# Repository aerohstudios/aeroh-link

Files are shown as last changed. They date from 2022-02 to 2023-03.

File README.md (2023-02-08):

# Aeroh Link

Internet Connected Infrared Remote for Alexa, Google Assitant, Apple Homekit (Siri) &amp; IFTTT integration

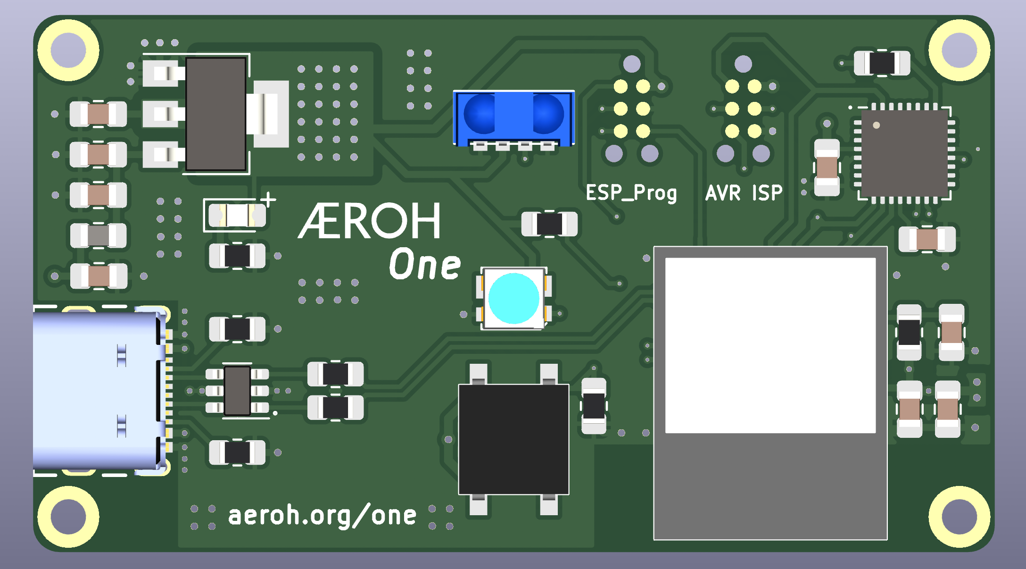
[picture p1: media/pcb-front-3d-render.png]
PCB Front 3D Render


## Description

The Aeroh Link is for the lazy people, the exhausted ones who can't be bothered to turn on their fans because they have to get out of the couch.

Aeroh Link is an internet-connected device that turns your tower fan into a smart fan. You can either use our mobile app or simply integrate it into your Alexa, Google Assistant, Siri, or IFTTT. And at 10th the price of a smart fan.

It doesn't end there. Aeroh Link can work with a wide range of tower fans in the market and it's adaptable to work with any device that can be controlled with remote control. Yes, even with your old TV.

Aeroh Link has a small footprint; it mounts on top of the infra-red remote receiver of your equipment and is programmed to emit the remote signals based on what your equipment can understand. We have a wide range of mounting options that you can either order or freely download the 3D models and print yourself if you have access to a 3D printer.

Moreover, You can still use your OEM remote while Aeroh Link is mounted on the equipment. This is because Aeroh One has an infra-red remote receiver in the front, and it can proxy the signals that it receives.

With this infra-red remote receiver, you can also record custom infra-red signals and program the Aeroh Link to work with new equipment.

With Aeroh Link, make your smart home smarter, and that too without breaking your bank!

## Photo Gallery

### Enclosure

**Front of the enclosure with IR Receiver Window, Status LED window and control button**

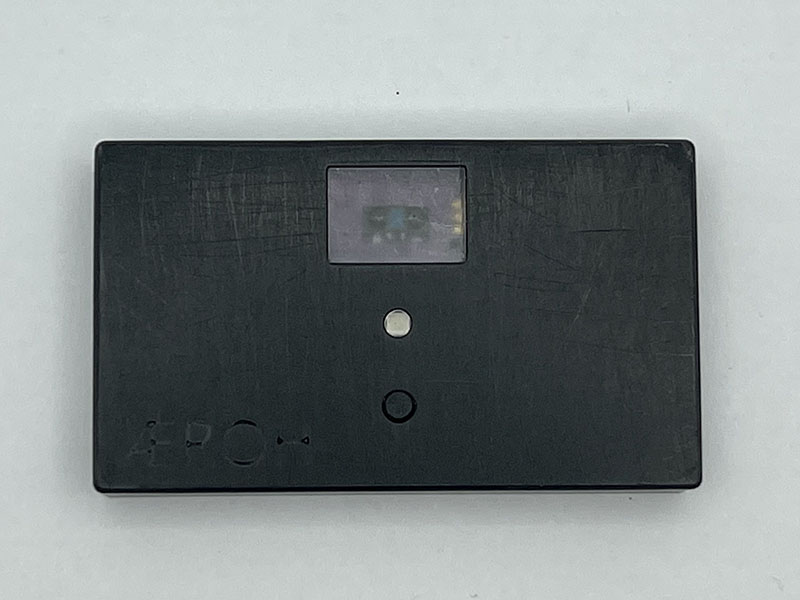
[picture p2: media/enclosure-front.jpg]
Enclosure Front


**Back of the enclosure with IR Emitter**

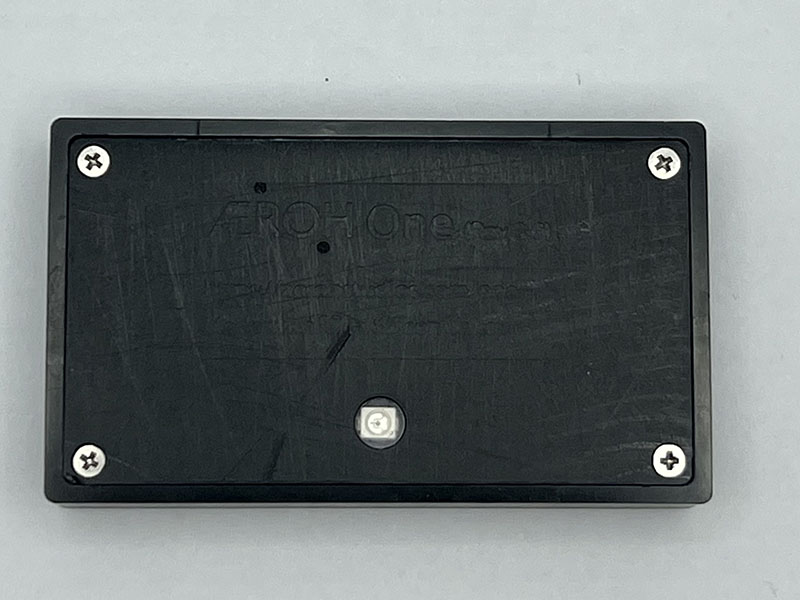
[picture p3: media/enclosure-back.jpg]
Enclosure Back


**USB-C Port for Power & Debugging**

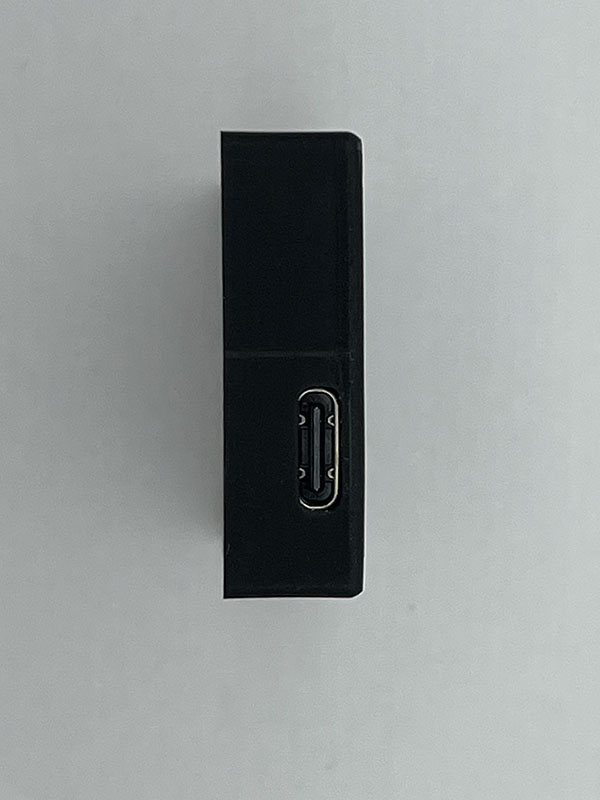
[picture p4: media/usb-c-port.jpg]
USB-C Port


### PCB

**Front of the PCB with IR Receiver, Status LED, control button**

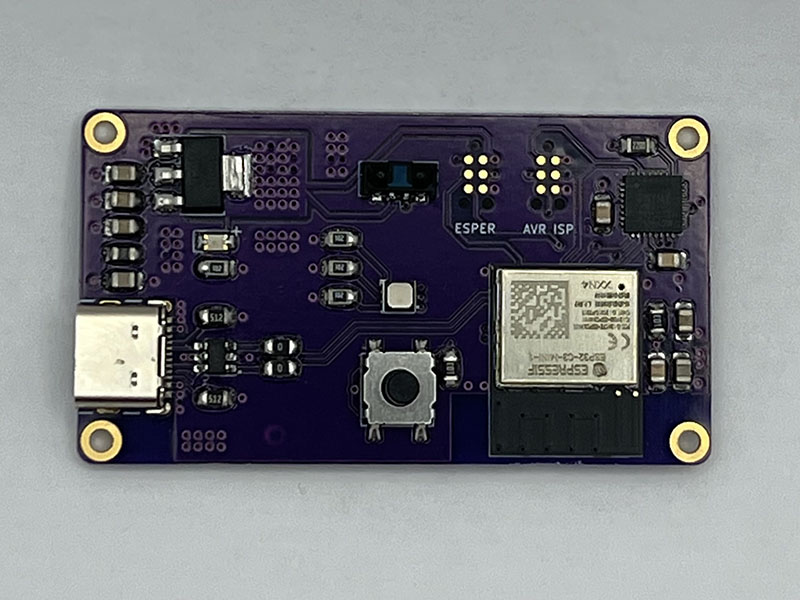
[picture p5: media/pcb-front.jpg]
PCB Front


**Back of the PCB with IR Emitter**

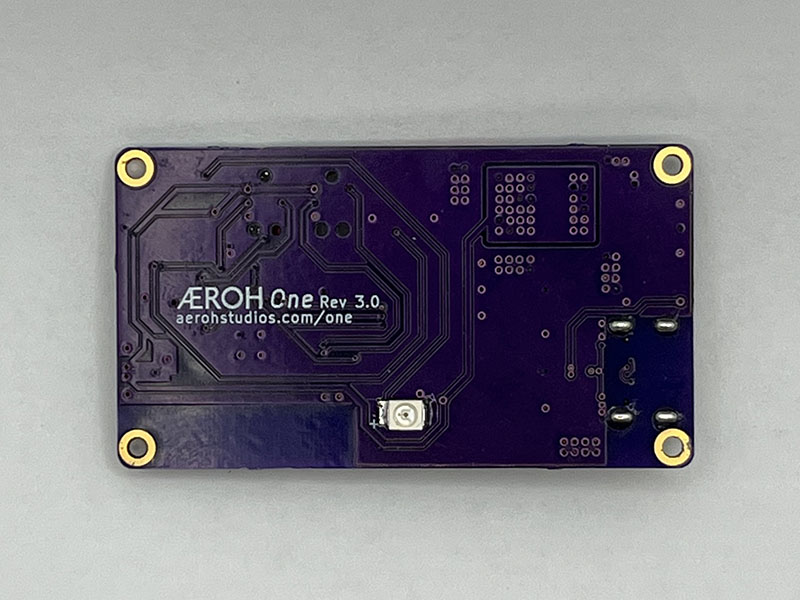
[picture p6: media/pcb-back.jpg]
PCB Back


## Directory Structure

- `/case`: CAD Files for printing the enclosure or assist with custom mounts for the enclosure
- `/code`: Firmware for the Wireless Connectivity, Infrared Remote Rx/Tx, and Mobile Apps
- `/pcb`: Gerber files and schematic for PCB design and production1

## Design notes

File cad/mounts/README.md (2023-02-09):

# Aeroh Link Mounting Adapter

Different types of mounting adapters for Aeroh Link to support various types surfaces. 

**Flex Mounts**

Flex Mounts are very versatile. Here are some tips on how to print them:

1. Print flex mounts with a flexible matrial like TPU. We tried [SainSmart Black TPU](https://www.amazon.com/SainSmart-Flexible-Printing-Filament-Dimensional/dp/B00TI3JUTM/) and it was easy to print with, and we were happy with the print quality.
2. Our flex mounts are multi part designs, so that you can mix and match materials. Import them as multipart print into your slicer, and they should align themselves properly.

## Support

Please feel free to create a Github issue if you need help or facing challenges. 

## Contribute

User contributions are welcome. Please upload files in `.3mf` format, and a photo (`.jpg`, under 300KB) of the mount.

The enclosure design is in [/cad/case](/cad/case) directory. You can grab dimentions for the Aeroh Link enclosure from [/cad/case/Aeroh_Link_Autodesk_Parameters.csv](/cad/case/Aeroh_Link_Autodesk_Parameters.csv) file. If you use [Parameter I/O](https://apps.autodesk.com/FUSION/en/Detail/Index?id=1801418194626000805&appLang=en&os=Win64) plugin for Fusion 360, the CSV file can directly be imported.

## Examples

1. Rigid Mount for Tower Fans
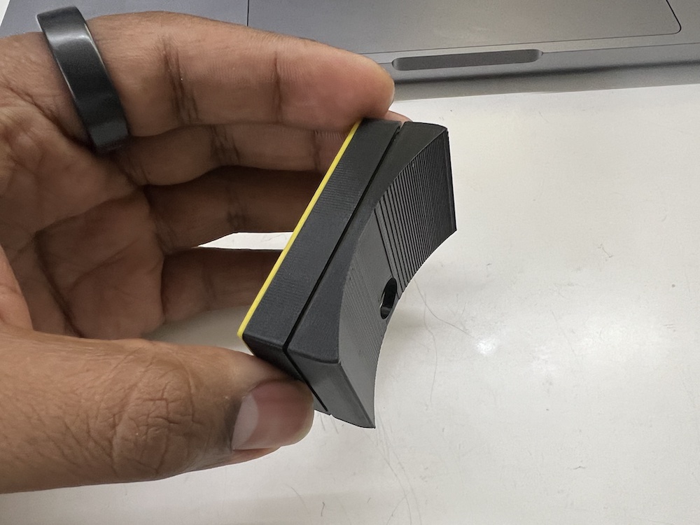
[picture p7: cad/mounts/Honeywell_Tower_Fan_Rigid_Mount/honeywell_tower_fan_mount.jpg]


1. Flex Mount with Small Footprint
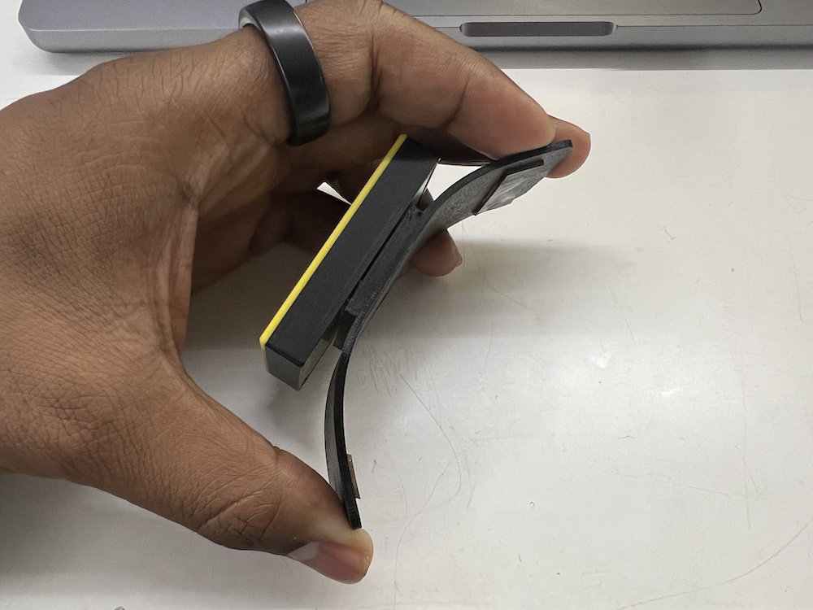
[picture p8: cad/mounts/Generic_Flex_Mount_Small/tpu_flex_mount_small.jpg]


1. Flex Mount with Large Footprint
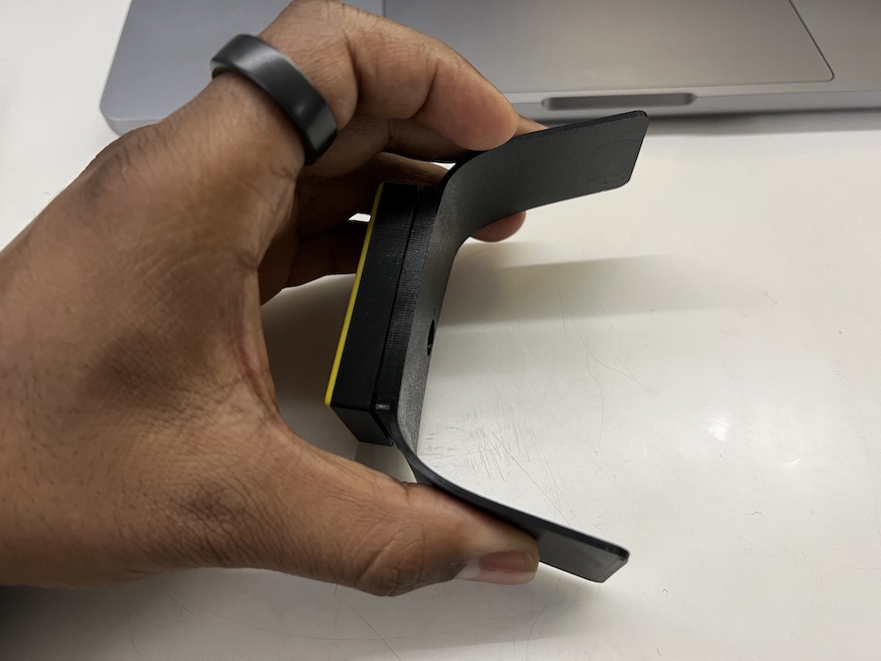
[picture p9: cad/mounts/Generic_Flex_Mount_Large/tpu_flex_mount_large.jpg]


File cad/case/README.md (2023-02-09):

# Aeroh Link Enclosure Files

Aeroh Link Enclosure has two seperate parts -- Front, and Back. You can find respective files in `back_panel` and `back_panel` directories.

These are multipart files, so you will have to import them as multi part files in to your Slicer software, and the parts should align themselves properly.

## Support

Please feel free to create a Github issue if you need help or facing challenges. 

## Contribute

User contributions are welcome. Please upload files in `.3mf` format, and a photo (`.jpg`, under 300KB) of the enclosure.

## Photos

**Front**
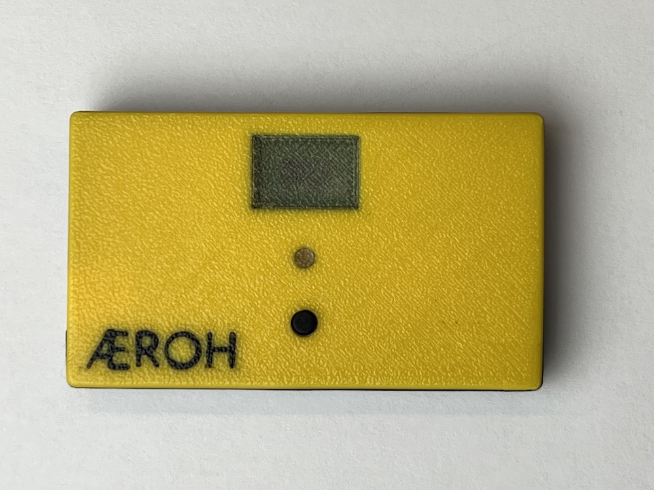
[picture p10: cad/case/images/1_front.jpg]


**Back**
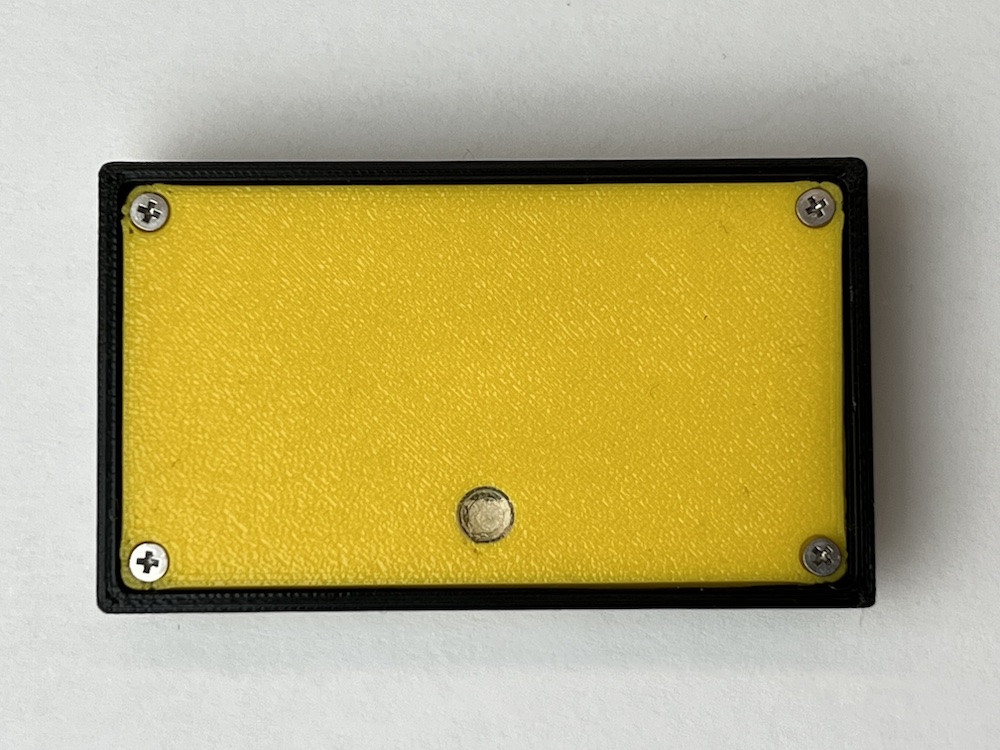
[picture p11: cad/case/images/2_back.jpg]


**USB Slot**
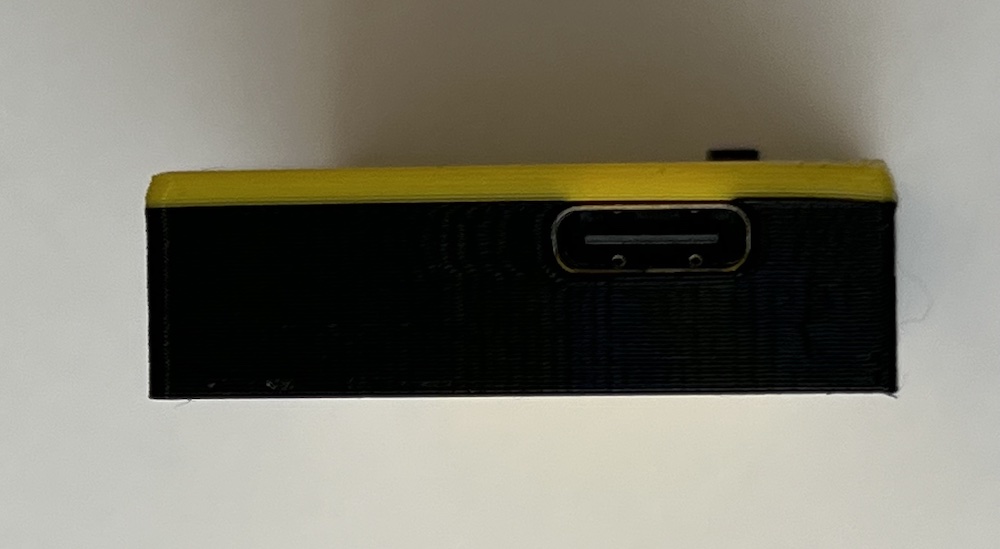
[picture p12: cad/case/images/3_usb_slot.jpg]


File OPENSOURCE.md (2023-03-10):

# Aeroh Link Open Source Resources

## API Documentation
[https://apidocs.aeroh.org/docs/cloud/v1](https://apidocs.aeroh.org/docs/cloud/v1)

## Firmware
[code/esp32-core](code/esp32-core)

## Schematic 
[pcb/Aeroh_One_Schematic_Rev_1.3.2.pdf](pcb/Aeroh_One_Schematic_Rev_1.3.2.pdf)

## Bill of Materials
[main/pcb/Aeroh_One_BOM.csv](pcb/Aeroh_One_BOM.csv)

## Enclosure Design
[case](cad/case)

## Mounting Adapters 
[mounts](cad/mounts)

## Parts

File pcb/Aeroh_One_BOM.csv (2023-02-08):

Reference(s) | Value | DigiKey Part No | Manufacturer Part No | Datasheet
C1 | 2u2 | 490-14467-1-ND | GRM21BR71E225KE11L | https://search.murata.co.jp/Ceramy/image/img/A01X/G101/ENG/GRM21BR71E225KE11-01.pdf
C2 | 2u2 | 490-14467-1-ND | GRM21BR71E225KE11L | https://search.murata.co.jp/Ceramy/image/img/A01X/G101/ENG/GRM21BR71E225KE11-01.pdf
C3 | 22u | 490-10511-1-ND | GRM21BR61A226ME51L | https://search.murata.co.jp/Ceramy/image/img/A01X/G101/ENG/GRM21BR61A226ME51-01.pdf
C4 | 22u | 490-10511-1-ND | GRM21BR61A226ME51L | https://search.murata.co.jp/Ceramy/image/img/A01X/G101/ENG/GRM21BR61A226ME51-01.pdf
C7 | 22u | 490-10511-1-ND | GRM21BR61A226ME51L | https://search.murata.co.jp/Ceramy/image/img/A01X/G101/ENG/GRM21BR61A226ME51-01.pdf
C8 | 100n | 490-11955-1-ND | GCD21BR71H104KA01L | https://www.murata.com/-/media/webrenewal/support/library/catalog/products/capacitor/ceramiccapacitor/c03e.ashx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
C9 | 100n | 490-11955-1-ND | GCD21BR71H104KA01L | https://www.murata.com/-/media/webrenewal/support/library/catalog/products/capacitor/ceramiccapacitor/c03e.ashx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
C10 | 100n | 490-11955-1-ND | GCD21BR71H104KA01L | https://www.murata.com/-/media/webrenewal/support/library/catalog/products/capacitor/ceramiccapacitor/c03e.ashx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
C11 | 100n | 490-11955-1-ND | GCD21BR71H104KA01L | https://www.murata.com/-/media/webrenewal/support/library/catalog/products/capacitor/ceramiccapacitor/c03e.ashx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
D1 | LED | 475-1278-1-ND | LS R976-NR-1 | https://dammedia.osram.info/media/resource/hires/osram-dam-5178068/LS%20R976_EN.pdf
D2 | SK6812MINI-B-001 | 1528-4957-ND | 4957 | https://cdn-shop.adafruit.com/product-files/4957/SK6812MINI-B-001__OP0108K__REV.A0__EN.pdf
D3 | TSMP77000 | TSMP77000TCT-ND | TSMP77000TT | https://www.vishay.com/docs/82478/tsmp77000.pdf
D4 | Kingbright_AA3528F3S | 754-1532-1-ND | AA3528P3S | https://www.kingbrightusa.com/images/catalog/SPEC/AA3528P3S.pdf
FB1 | 120R | 587-1747-1-ND | FBMH2012HM121-T | https://ds.yuden.co.jp/TYCOMPAS/ut/detail?pn=LSMGA201208T121RG&u=M
J1 | USB4105-GF-A | 2073-USB4105-GF-ACT-ND | USB4105-GF-A | https://gct.co/files/specs/usb4105-spec.pdf
J2 | AVR-ISP-6 | 1849-PR20B03VBDN-ND | PR20B03VBDN | https://media.metz-connect.com/files/171/Data_sheet_PR20BXXVBDN.PDF
J3 | ESP_Prog | 1849-PR20B03VBDN-ND | PR20B03VBDN | https://media.metz-connect.com/files/171/Data_sheet_PR20BXXVBDN.PDF
R1 | 5k1 | 311-5.10KCRCT-ND | RC0805FR-075K1L | https://www.yageo.com/upload/media/product/productsearch/datasheet/rchip/PYu-RC_Group_51_RoHS_L_11.pdf
R2 | 5k1 | 311-5.10KCRCT-ND | RC0805FR-075K1L | https://www.yageo.com/upload/media/product/productsearch/datasheet/rchip/PYu-RC_Group_51_RoHS_L_11.pdf
R3 | 1k | 311-1.00KCRCT-ND | RC0805FR-071KL | https://www.yageo.com/upload/media/product/productsearch/datasheet/rchip/PYu-RC_Group_51_RoHS_L_11.pdf
R4 | 1k | 311-1.00KCRCT-ND | RC0805FR-071KL | https://www.yageo.com/upload/media/product/productsearch/datasheet/rchip/PYu-RC_Group_51_RoHS_L_11.pdf
R5 | 1k | 311-1.00KCRCT-ND | RC0805FR-071KL | https://www.yageo.com/upload/media/product/productsearch/datasheet/rchip/PYu-RC_Group_51_RoHS_L_11.pdf
R6 | 10k | 311-10.0KCRCT-ND | RC0805FR-0710KL | https://www.yageo.com/upload/media/product/productsearch/datasheet/rchip/PYu-RC_Group_51_RoHS_L_11.pdf
R12 | 10k | 311-10.0KCRCT-ND | RC0805FR-0710KL | https://www.yageo.com/upload/media/product/productsearch/datasheet/rchip/PYu-RC_Group_51_RoHS_L_11.pdf
R16 | 10k | 311-10.0KCRCT-ND | RC0805FR-0710KL | https://www.yageo.com/upload/media/product/productsearch/datasheet/rchip/PYu-RC_Group_51_RoHS_L_11.pdf
R17 | 220R | 311-220CRCT-ND | RC0805FR-07220RL | https://www.yageo.com/upload/media/product/productsearch/datasheet/rchip/PYu-RC_Group_51_RoHS_L_11.pdf
S1 | C&K_PTS526_SK15_SMTR2_LFS | CKN12221-1-ND | PTS526 SK15 SMTR2 LFS | https://www.ckswitches.com/media/2780/pts526.pdf
U2 | USBLC6-2SC6 | 497-2525-1-ND | DALC208SC6 | https://www.st.com/resource/en/datasheet/usblc6-2.pdf
U3 | AMS1117-3.3 | AZ1117IH-3.3TRG1DICT-ND | AZ1117IH-3.3TRG1 | http://www.advanced-monolithic.com/pdf/ds1117.pdf
U4 | ESP32-C3-MINI-1 | 1965-ESP32-C3-MINI-1-N4CT-ND | ESP32-C3-MINI-1-N4 | https://www.espressif.com/sites/default/files/documentation/esp32-c3-mini-1_datasheet_en.pdf
U5 | ATtiny167-MU | ATTINY167-MU-ND | ATTINY167-MU | http://ww1.microchip.com/downloads/en/DeviceDoc/Atmel-8265-8-bit-AVR-Microcontroller-tinyAVR-ATtiny87-ATtiny167_datasheet.pdf

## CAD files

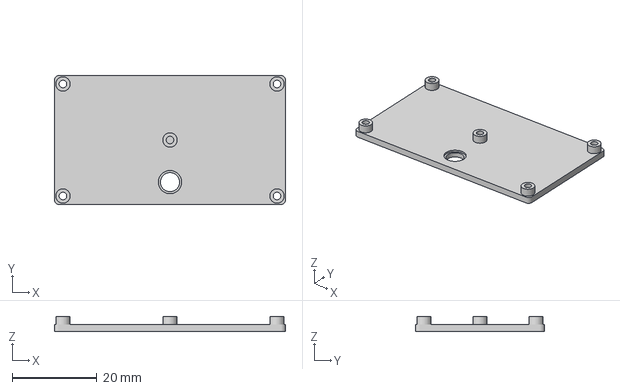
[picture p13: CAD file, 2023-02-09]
cad/case/back_panel/backpanel.3mf
54.6 x 30.5 x 3.60 mm

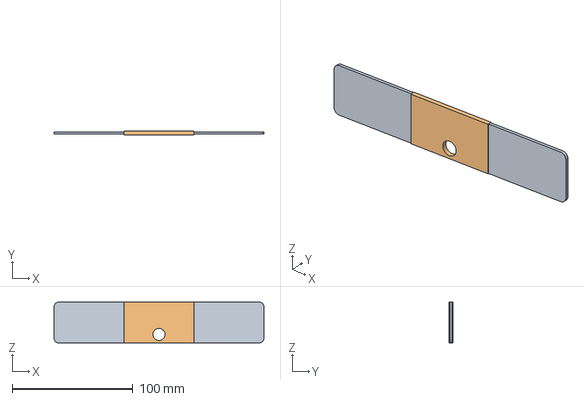
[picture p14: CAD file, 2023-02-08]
cad/mounts/Generic_Flex_Mount_Large/TPU_Flex_Mount_v4_Large__Flex_Side.3mf
174.0 x 3.00 x 33.8 mm
Aeroh Link TPU Flex Mount v4 Large_Aeroh Link TPU Flex Mount v4_Aeroh Link TPU Flex Mount Flex Side
Aeroh Link TPU Flex Mount v4 Large_Aeroh Link TPU Flex Mount v4_Aeroh Link TPU Flex Mount Rigid Side

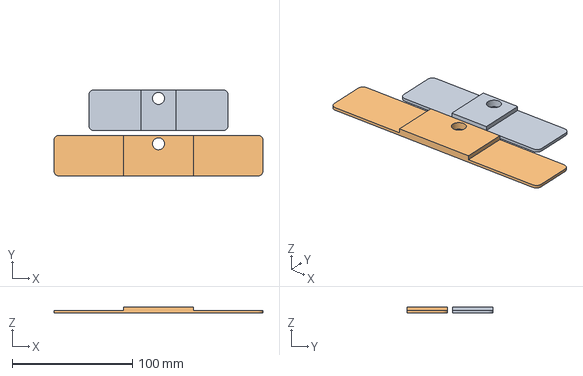
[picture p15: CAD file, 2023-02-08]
cad/mounts/Generic_Flex_Mount_Small/TPU_Flex_Mount_v4_Small__Rigid_Side.3mf
174.0 x 71.6 x 5.00 mm
Aeroh Link TPU Flex Mount v4 Small_Aeroh Link TPU Flex Mount v4_Aeroh Link TPU Flex Mount Rigid Side
Aeroh Link TPU Flex Mount v4 Large_Aeroh Link TPU Flex Mount v4_Aeroh Link TPU Flex Mount Flex Side

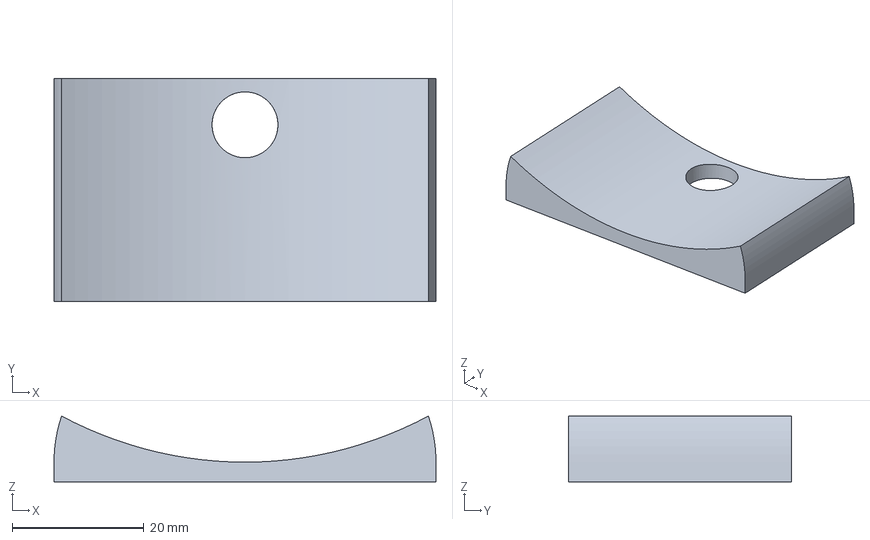
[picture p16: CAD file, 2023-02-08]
cad/mounts/Honeywell_Tower_Fan_Rigid_Mount/Honeywell_Tower_Fan_Aeroh_Link_Mount_v4.3mf
58.0 x 33.8 x 10.0 mm

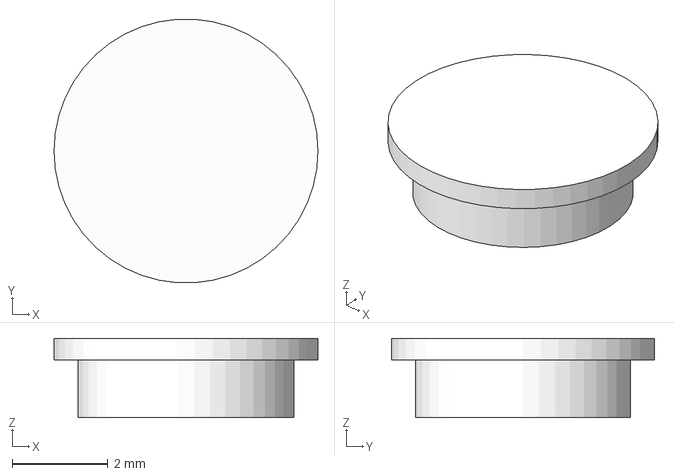
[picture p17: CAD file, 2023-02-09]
cad/case/back_panel/ir_emit_lens.3mf
5.50 x 5.49 x 1.65 mm

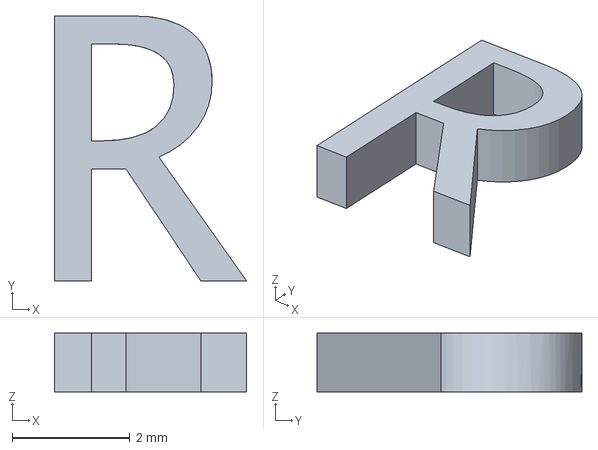
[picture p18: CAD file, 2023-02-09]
cad/case/front_enclosure/enclosure_front_plate_text_2_R.3mf
3.27 x 4.51 x 1.00 mm

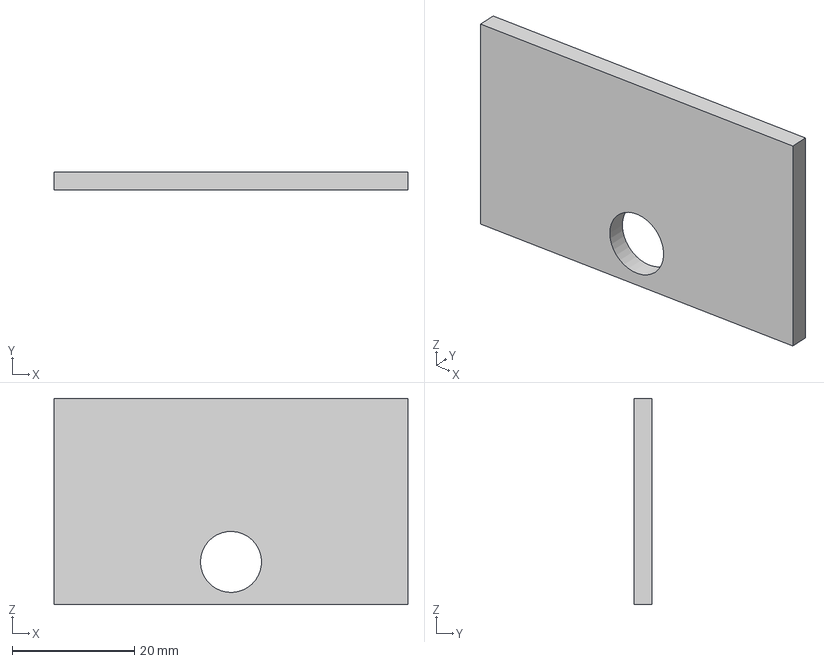
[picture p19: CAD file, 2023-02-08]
cad/mounts/Generic_Flex_Mount_Large/TPU_Flex_Mount_v4_Large__Rigid_Side.3mf
58.0 x 3.00 x 33.8 mm

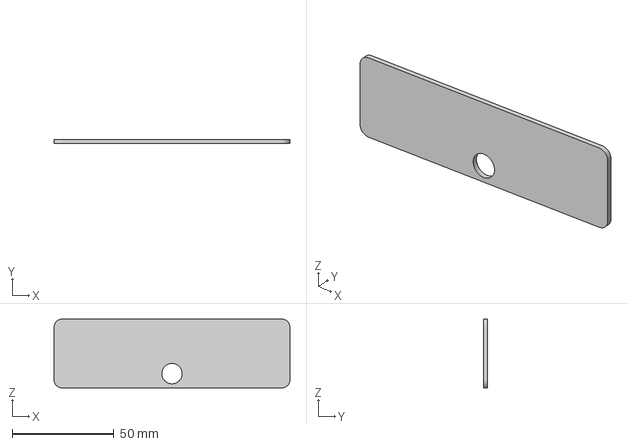
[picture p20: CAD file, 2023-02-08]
cad/mounts/Generic_Flex_Mount_Small/TPU_Flex_Mount_v4_Small__Flex_Side.3mf
116.0 x 2.00 x 33.8 mm

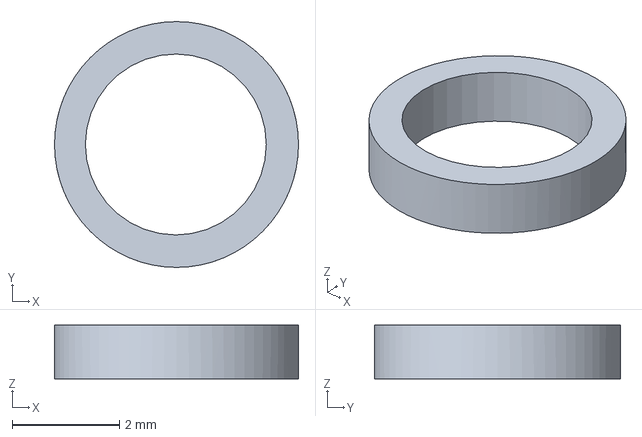
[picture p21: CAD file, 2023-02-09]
cad/case/front_enclosure/enclosure_front_plate_text_3_O.3mf
4.55 x 4.58 x 1.00 mm

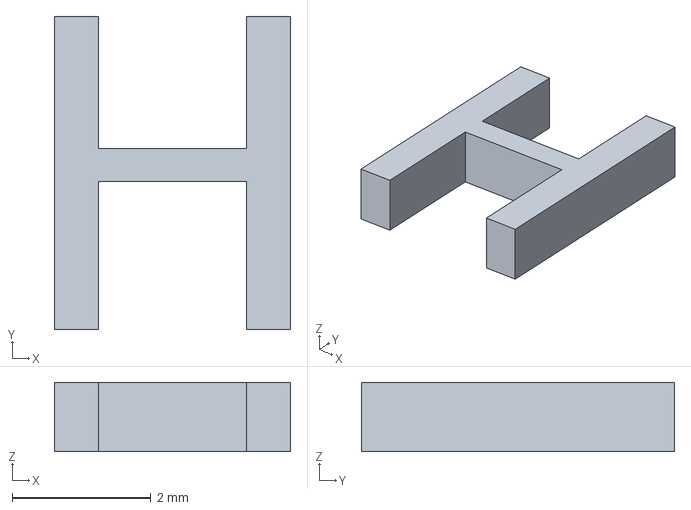
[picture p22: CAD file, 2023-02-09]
cad/case/front_enclosure/enclosure_front_plate_text_4_H.3mf
3.40 x 4.51 x 1.00 mm

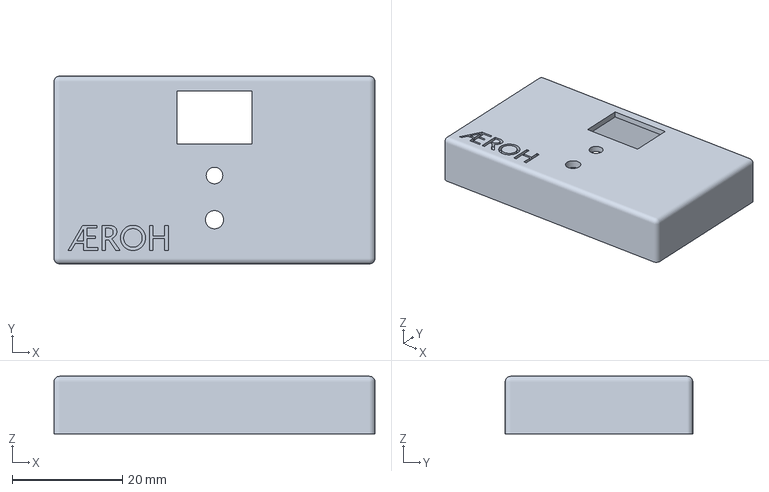
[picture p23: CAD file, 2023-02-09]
cad/case/front_enclosure/enclosure_front_plate.3mf
58.1 x 34.0 x 10.4 mm

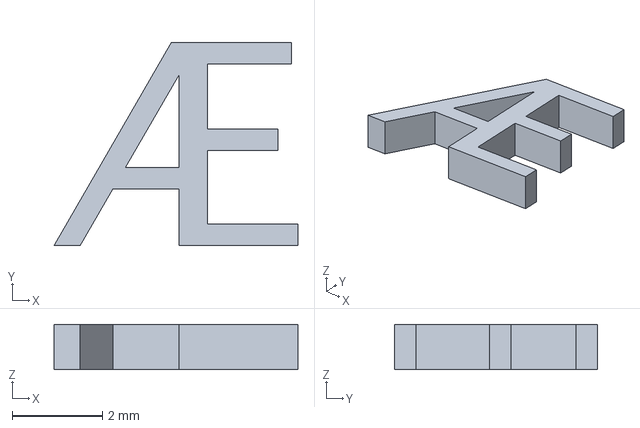
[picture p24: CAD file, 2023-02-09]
cad/case/front_enclosure/enclosure_front_plate_text_1_AE.3mf
5.41 x 4.51 x 1.00 mm

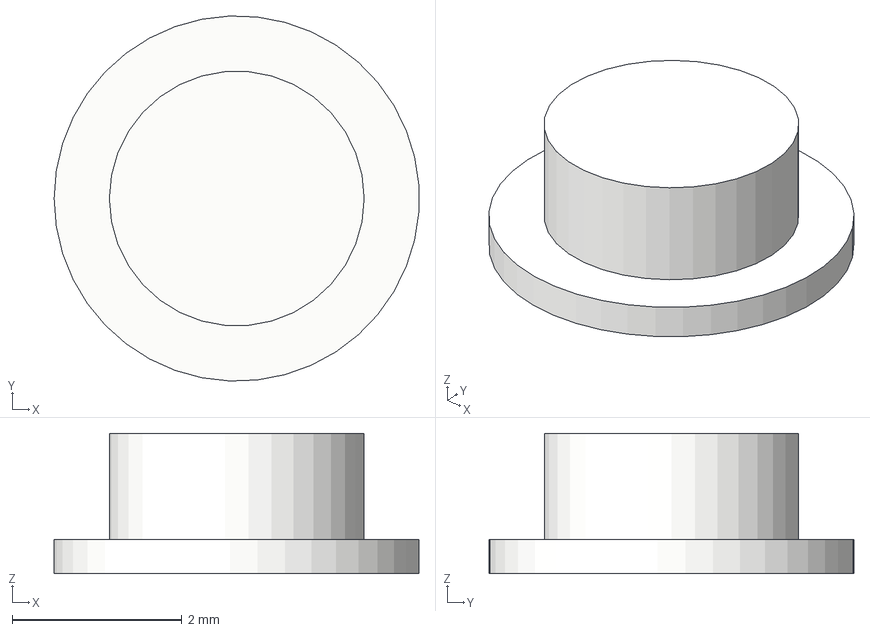
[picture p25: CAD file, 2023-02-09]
cad/case/front_enclosure/rgb_led_lens.3mf
4.29 x 4.30 x 1.65 mm

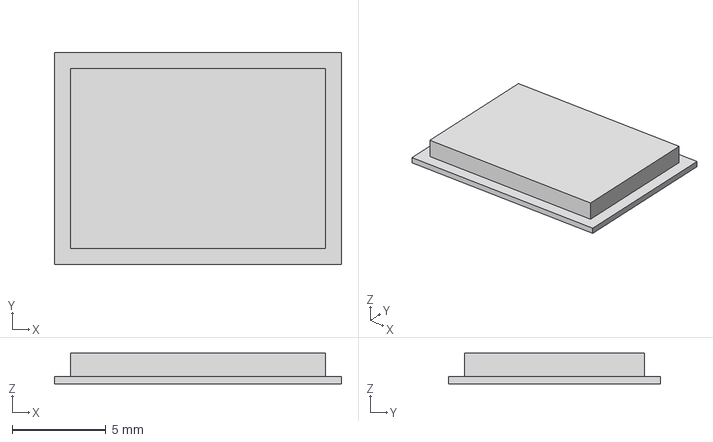
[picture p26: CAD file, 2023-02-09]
cad/case/front_enclosure/ir_recv_lens_flush.3mf
15.3 x 11.3 x 1.65 mm

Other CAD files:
cad/case/front_enclosure/enclosure_front_plate_screw_mount_4.3mf
cad/case/front_enclosure/enclosure_front_plate_screw_mount_3.3mf
cad/case/front_enclosure/enclosure_front_plate_screw_mount_1.3mf
cad/case/front_enclosure/enclosure_front_plate_screw_mount_2.3mf

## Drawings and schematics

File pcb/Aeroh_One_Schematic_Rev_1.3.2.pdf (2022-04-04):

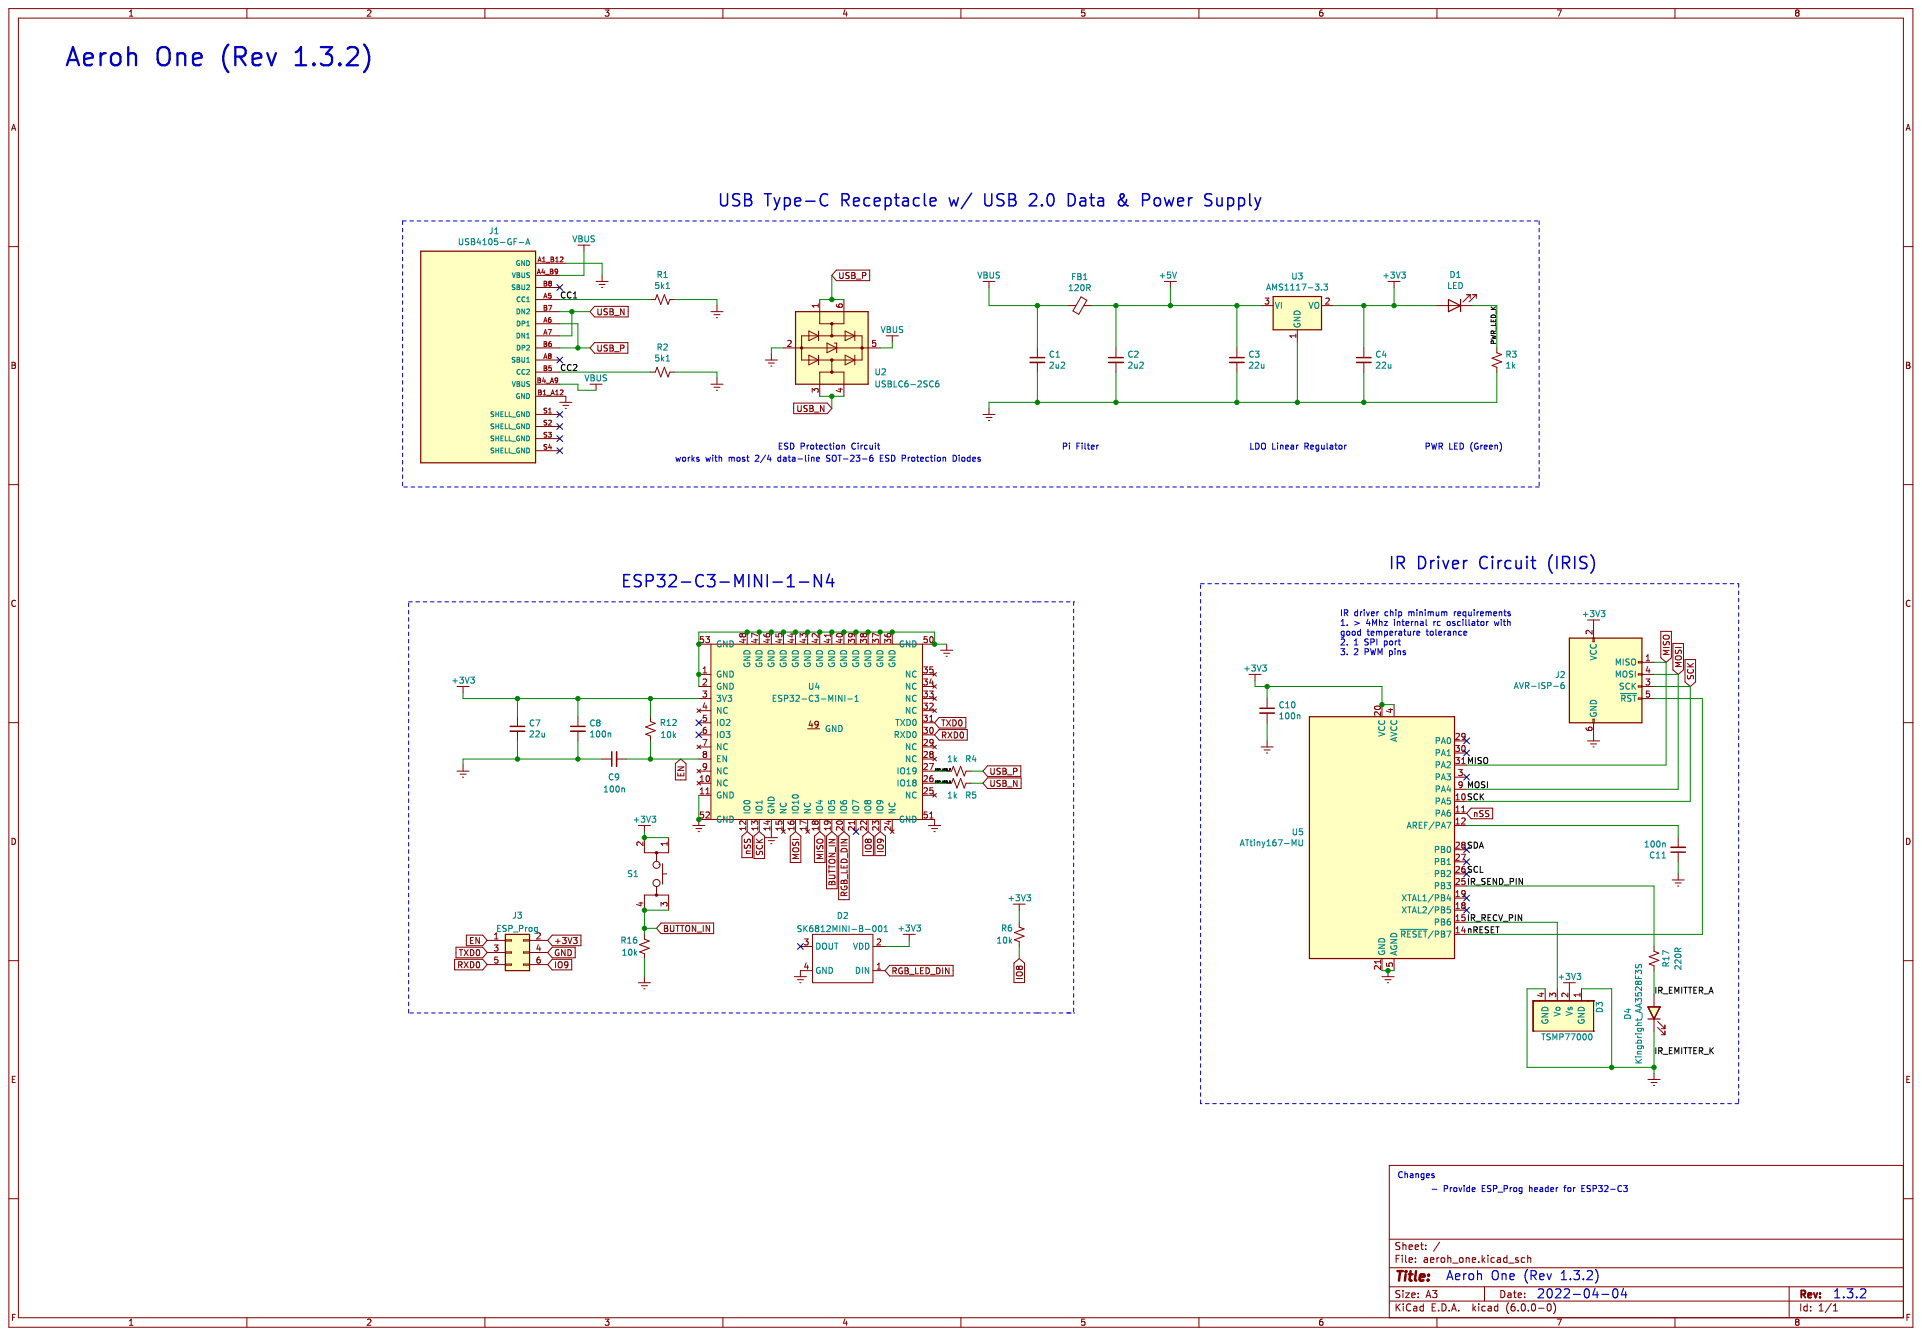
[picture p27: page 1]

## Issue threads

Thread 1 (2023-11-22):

Wish:  the kicad files

stappersg, 2023-11-22:
Please publish in addition to the PDF also the KiCAD files.

shivdeepak, 2023-11-22:
@stappersg, thanks for asking :)

I wanted to upload them yesterday, but the files are on a different computer and a local NAS, and I don't have access to them right now. I can upload them in a few weeks.

How are you planning on using them, if you are planning to send them from fabrication and assembly, may I offer to send prefabricated and assembled board that I already have? Unfortunately, It will take a me few weeks to ship as well. :(

stappersg, 2023-11-22:
On Wed, Nov 22, 2023 at 10:13:50AM -0800, Shiv Deepak Muddada wrote:
> @stappersg, thanks for asking :)

    :-)

> I wanted to upload them yesterday,

Great minds think alike

> but the files are on a different computer and a local NAS, and I don't
> have access to them right now.

Acknowledge

> I can upload them in a few weeks.

OK, please do.

> How are you planning on using them,

Study / learn  /  explore  /  glare.

Having the same source files as the designer makes it possible to things
you can't do from the .pdf.  Such as exporting  netlists, truely seeing
what is connected with what.

> if you are planning to send them from fabrication and assembly,
> may I offer to send prefabricated and assembled board that I already
> have? Unfortunately, It will take a me few weeks to ship as well. :(

I pas the offer to the next reader, to other readers.

Groeten
Geert Stappers
Somewhere in Europe
--
Silence is hard to parse

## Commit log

2022-04-04 Add schematic
2023-02-08 add bill of materials
    [Aeroh_One_BOM.csv]
2023-02-08 add 3d render of pcb from kicad
2023-02-08 changing directory structure to acomodate case designs and mount design files
2023-02-08 add bill of materials to opensource.md
2023-02-08 add different types of mounting adapters for aeroh link
    [Honeywell_Tower_Fan_Aeroh_Link_Mount_v4.3mf, TPU_Flex_Mount_v4_Large__Flex_Side.3mf, TPU_Flex_Mount_v4_Large__Rigid_Side.3mf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]
2023-02-09 add aeroh link enclosure files
    [Aeroh_Link_Autodesk_Parameters.csv, backpanel.3mf, enclosure_front_plate.3mf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]
2023-02-09 update mount adapter readme.md
